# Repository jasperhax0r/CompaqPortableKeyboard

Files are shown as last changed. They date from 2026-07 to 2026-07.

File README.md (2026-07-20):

# Compaq Portable Keyboard — Replacement PCB, Firmware & Protocol

A drop-in replacement keyboard controller for the **Compaq Portable** (1983),
built around a Raspberry Pi Pico. It reads an 83-key diode matrix and speaks the
machine's native **IBM XT (scancode set 1)** protocol over the original 2×3
keyboard connector.

The repo also contains a **USB-serial / PS-2 test rig** used during bring-up, and
— probably the most useful part for other people — a **scope-verified writeup of
the Compaq Portable keyboard protocol**, which as far as I can tell isn't
documented anywhere else public.

Everything here is hand-solderable through-hole where possible, on purpose. The
only surface-mount parts are the two level-shifter buffers, and even those have a
through-hole alternative described in the build notes.

---

## Why this exists

The original keyboard PCBs are getting old, and the matrix routing on the
factory board is... a journey. This recreates the keyboard's electrical behavior
faithfully enough that the machine POSTs and types exactly as it did in 1983,
while letting you rebuild the board with a $15 iron and a solder sucker.

The first PCB revision is a **faithful recreation** of the original layout, on
purpose — it's a known-good reference. A rev2 with layout improvements is planned
(see `docs/rev2-notes.md`).

---

## Repository layout

```
/firmware        Pico firmware (CircuitPython)
  code.py          matrix-scan keyboard firmware (the real thing)
  test-rig/        USB-serial + PS-2 bring-up firmware
/hardware        KiCad project, schematic, PCB, Gerbers
/models          3D-printable STLs (connector keyway + fitment shims)
/tools           protocol decoder + KLE matrix-annotation scripts
  xtframe.py       decode a logic-analyzer CSV into XT scancodes
  kle_annotate.py  annotate a raw KLE layout with matrix coordinates
/docs            protocol writeup, build notes, rev2 log
```

---

## How it works

The Pico scans a **10×10 diode matrix** (83 keys, one diode per key, so full
NKRO) and emits XT scancodes on the keyboard connector.

**Power:** the Compaq feeds ~12 V down the cable. An onboard 7805 drops that to
5 V for the buffers, and the Pico runs from that 5 V into VSYS through a Schottky.
The board reproduces the original's protection: reverse-polarity Schottky, a
polyfuse, TVS clamps at the connector, and a 5.6 V crowbar across the 5 V rail.

**Level shifting:** the Pico is 3.3 V and **not** 5 V tolerant. Outbound
clock/data go through an **SN74LVC07A** (open-drain, pulled to 5 V). Inbound
reset and clock-sense come back through an **SN74LVC14A** Schmitt-trigger
cascade — the hysteresis matters, see the protocol notes on line ringing.

**Protocol:** XT scancode set 1. The keyboard generates the clock; each frame is
one start bit plus 8 data bits, LSB first, with data valid on the falling clock
edge, at roughly 24 kHz. On reset release the keyboard waits ~170 ms then sends
`0xAA` (self-test passed). Full details and scope captures in
[`docs/protocol.md`](docs/protocol.md).

---

## Building the firmware

The firmware is **CircuitPython** — no toolchain, no compile step.

1. Flash CircuitPython to the Pico.
2. Copy `firmware/code.py` to the `CIRCUITPY` drive as `code.py`.
3. That's it — it runs on boot.

### Bring-up before you install it

`code.py` has debug switches at the top:

- `DEBUG = True` prints every key make/break to the USB serial console.
- `RAW_SCAN = True` prints the raw `(row, col)` of every press, ignoring the
  keymap — use this to verify your matrix wiring against the board.
- `XT_CONNECTED = False` scans and prints but does **not** drive the XT lines,
  so you can validate the whole matrix over USB with nothing connected to the
  Compaq.

Walk every key with `RAW_SCAN = True` and confirm it matches the board before
trusting the scancode map. When it checks out, set all three back to
`DEBUG = False`, `RAW_SCAN = False`, `XT_CONNECTED = True`.

> **Note on the matrix map:** this board is wired to the *original Compaq's*
> matrix order (a straight sequential fill), **not** the interleaved mapping a
> tool like `kbplacer` produces from the KLE. If you regenerate the keymap from
> the layout file you'll get the wrong table. The map in `code.py` is the
> authoritative one — it was verified key-by-key against the physical board.

---

## Building the board

See [`docs/build.md`](docs/build.md) for the full walkthrough. The short version:

1. **Populate and verify the regulator section first.** Confirm 5.0 V at the rail
   *and* at the buffer VCC pins before any logic sees power.
2. **Power up on a current-limited bench supply** (~150 mA limit) for the first
   power-on. A wiring fault then shows as the supply hitting its limit at ~0 V,
   instead of as a hot regulator and a burn. (Ask me how I know.)
3. Then the Pico, then the level shifters, then the matrix.

The two `SN74LVC0x` buffers are TSSOP — the only fine-pitch parts. Drag-solder
with plenty of flux and wick any bridges. If you'd rather stay all-through-hole,
`docs/build.md` covers a `7407` + `CD4050B` DIP alternative (you lose the Schmitt
hysteresis on the input side, fine for a short cable).

---

## The 3D-printed parts

`/models` has the connector **keyway** (the original connector is mechanically
keyed; the print replicates that so the plug can't seat rotated — important,
since a rotated plug puts 12 V onto a signal line) and **fitment shims**.

Print in any rigid filament. PETG or ABS if it'll sit near the warm regulator;
PLA is fine otherwise.

---

## Tools

`tools/xtframe.py` decodes a logic-analyzer CSV (start bit + 8 data LSB-first,
falling-edge sampled) into XT scancodes, with a `--deglitch-us` option to reject
sub-threshold ringing on a passive tap. It was used to reverse-engineer the
protocol; it's handy for anyone probing an XT-family keyboard.

`tools/kle_annotate.py` annotates a raw [keyboard-layout-editor](https://www.keyboard-layout-editor.com)
JSON with matrix coordinates.

---

## Status

Working. The board POSTs and types on a real Compaq Portable. Known rev1
warts and the planned rev2 fixes are logged in [`docs/rev2-notes.md`](docs/rev2-notes.md)
(regulator thermal pad, hand-solder footprints, silkscreen polarity markers,
axial diode on the 5 V rail, and more).

---

## Licenses

This project is open-source hardware. Different parts carry different licenses,
because software, hardware, and documentation are legally distinct:

| Part | License |
|---|---|
| Firmware & tools (`/firmware`, `/tools`) | **MIT** |
| Hardware & 3D models (`/hardware`, `/models`) | **CERN-OHL-S v2** |
| Documentation (`/docs`, this README) | **CC-BY-4.0** |

- The **firmware** is MIT — use it however you like.
- The **board and STL designs** are CERN-OHL-S (strongly reciprocal): if you
  make and distribute modified hardware, keep the design files open under the
  same terms.
- The **documentation and protocol writeup** are CC-BY-4.0 — reproduce and build
  on them, with attribution.

Full texts are in `/LICENSES`. See CERN-OHL-S §3 for the source-availability
requirement when distributing hardware based on this design.

---

## Acknowledgements

Original Compaq Portable schematic reference: Howard W. Sams & Co.
Computerfacts, 1987 (used for cross-referencing switch designations during
reverse engineering).

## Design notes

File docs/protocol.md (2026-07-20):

# Compaq Portable Keyboard Protocol

A scope-verified description of the keyboard protocol used by the **Compaq
Portable** (1983). Everything here was measured on a working original keyboard
with a logic analyzer, not taken from a datasheet — where a number is quoted, it
came off the wire.

The short version: it's **IBM XT (scancode set 1)**, clocked by the keyboard,
with one detail that trips people up (see [Reset](#reset-active-low-host-driven)).

---

## Connector

The keyboard attaches with a **2×3 connector** (AMP), of which **5 of 6
positions are populated**. It is **mechanically keyed** — the housing physically
prevents the plug from seating rotated. This matters: the +12 V and signal pins
are adjacent, so a rotated plug would put 12 V onto a logic line.

| Pin | Function |
|-----|---|
| 1 | CLOCK |
| 2 | DATA |
| 3 | RESET |
| 4 | *(unpopulated)* |
| 5 | +12 V |
| 6 | GND |

> Pin numbering follows the board footprint. The clock/data assignment
> (pin 1 = clock, pin 2 = data) was **confirmed on the scope** — it is the
> reverse of what you might guess from the schematic, so verify before trusting
> a pinout diagram.

The unpopulated position (pin 4) has no conductor; the single ground is on pin 6.
Because the connector is keyed, there is no polarity protection from the pinout
itself — the board provides reverse-polarity protection instead.

---

## Electrical

- **12 V** supply down the cable. Everything on the keyboard PCB runs on 5 V
  behind a 78M05 regulator; the logic is 5 V.
- CLOCK and DATA are **open-collector, idle high**, with pull-ups on the
  keyboard board (~3.3 kΩ) and Schmitt-trigger receivers (74LS132 on the
  original). The Schmitt hysteresis is not decorative — see
  [Signal integrity](#signal-integrity).
- The keyboard's controller is an **8048-family** microcontroller
  (mask part `22-908-03A`) on a 4.6 MHz crystal — the same family as the
  IBM XT keyboard. The `RESET`, `PSEN`, and `ALE` pin labels on the schematic
  match an 8048 exactly (Compaq renamed ALE to "KBALE").

---

## Frame format

The **keyboard generates the clock.** Each byte is sent as:

```
        start   d0   d1   d2   d3   d4   d5   d6   d7
DATA  ──┐ 1  ┌──┐    ┌────┐ ...                      idle high
        └────┘  └────┘    └──
CLOCK ─┐  ┌─┐  ┌─┐  ┌─┐  ┌─┐  ...   ┌─────────────── idle high
       └──┘ └──┘ └──┘ └──┘ └──┘     ┘
         ^    ^    ^    ^
       data sampled on each FALLING edge
```

- **1 start bit** (value `1`), then **8 data bits, LSB first**.
- **Data is valid on the falling edge of CLOCK** — the host samples there.
- Idle state is CLOCK high, DATA high.

Measured bit period during a real transmission: **~41 µs (≈24.3 kHz)**. The host
is edge-driven, not timed, so exact frequency is not critical — but reproduce
the frame *shape* and edge relationship.

### Scancodes

Standard **XT scancode set 1**. A key press sends its **make code**; a key
release sends the **break code**, which is `make | 0x80` (bit 7 set).

Example, verified on the wire (key `A`):

```
make  0x1E
break 0x9E     (0x1E | 0x80)
```

The full make-code table for this keyboard is in the firmware
(`firmware/code.py`, the `KEYMAP` dict). Note that the *matrix position* → key
mapping is specific to this board's wiring; the *scancodes* are stock XT set 1.

---

## Reset (active-low, host-driven)

This is the detail that isn't obvious and will cost you an afternoon if you get
it wrong.

**RESET is active low and driven by the host**, not by the keyboard. The host
holds the line **low** during power-up and **releases it high** when it is ready
for the keyboard. On the original board this same node also carries the
keyboard's own power-on reset RC (≈33 kΩ / 39 µF), so it serves double duty.

For an emulator you do not have an 8048 reset pin to hold — you only need to
**read** this line and react to the low→high transition.

| Line state | Meaning |
|---|---|
| LOW  | host asserting reset — do not transmit |
| HIGH | normal operation |

---

## Power-on handshake (BAT)

Captured cold-boot sequence, keyboard attached, from power-on:

1. Host holds **RESET low** from power-on.
2. The keyboard's 8048 boots and emits a brief burst of clock/data garbage
   **while reset is still low** (the host isn't listening yet — ignore it).
3. Host **releases RESET high**.
4. The keyboard waits **~172 ms**, then clocks out **`0xAA`** (BAT — basic
   assurance test passed): start bit + `0xAA` LSB-first, falling-edge data,
   at 24.3 kHz.
5. The host accepts it and POST continues.

The ~172 ms delay is real and matters — some XT-family BIOSes miss the BAT byte
if it arrives too soon after reset release. Reproduce the delay.

```
reset released:  t = 2.5198 s
BAT frame (0xAA): t = 2.6916 s
delay:           172 ms
```

Raw capture: [`captures/keyboardboot.csv`](captures/keyboardboot.csv).

---

## Host inhibit

XT clock is bidirectional in the sense that the **host can pull CLOCK low to
inhibit** the keyboard (tell it to hold transmission). The 8048 reads the clock
line back on its `T1` test input to see this. An emulator should likewise sense
the clock line and buffer keystrokes while the host is holding it low, sending
them once the line is released.

---

## Signal integrity

During reverse engineering, some captured frames showed **extra clock edges** —
10 or 11 edges where a clean frame has 9 — decoding to garbage. These were not
keyboard faults. The keyboard's clock line **rings**, and a logic analyzer
sampling against a single threshold catches the sub-threshold crossings that the
original's **74LS132 Schmitt-trigger receivers reject**.

Two lessons:

1. When decoding captures from a passive tap, deglitch the clock edges (reject
   any falling edge closer than ~20 µs to the previous one — a real bit is
   ~41 µs). `tools/xtframe.py --deglitch-us 20` does this.
2. **Any receiver for this signal needs Schmitt hysteresis.** The replacement
   board uses an SN74LVC14A on the clock-sense and reset inputs for exactly this
   reason. A plain buffer would pass the ringing straight through.

This also explains the original's design: the series diodes and the 33 pF cap on
the reset line, and the 3.3 kΩ pull-ups, are all there to damp a two-foot coiled
cable running next to a CRT. Keep that philosophy — slow, weak, and damped is
what makes this link reliable. Don't speed up the edges.

---

## Decoding your own captures

`tools/xtframe.py` takes a logic-analyzer CSV with columns
`Time[s], CLOCK, DATA, RESET` and prints decoded scancodes:

```
python3 xtframe.py capture.csv --deglitch-us 20
```

It reports reset edges, clusters frames on inter-frame gaps, samples DATA on each
CLOCK falling edge, checks the start bit, and decodes LSB-first to a byte. A
frame with more than 9 edges or non-uniform bit periods is a glitch artifact, not
a scancode.

---

## Summary table

| Property | Value |
|---|---|
| Encoding | XT scancode set 1 |
| Clock source | keyboard |
| Bit order | LSB first |
| Frame | 1 start bit + 8 data bits |
| Data valid | falling edge of CLOCK |
| Bit rate | ~24.3 kHz (~41 µs/bit) |
| Idle | CLOCK high, DATA high |
| Break code | make \| 0x80 |
| Reset | active low, host-driven |
| Power-on | ~172 ms after reset release, send 0xAA |
| Host inhibit | host pulls CLOCK low; keyboard senses and buffers |

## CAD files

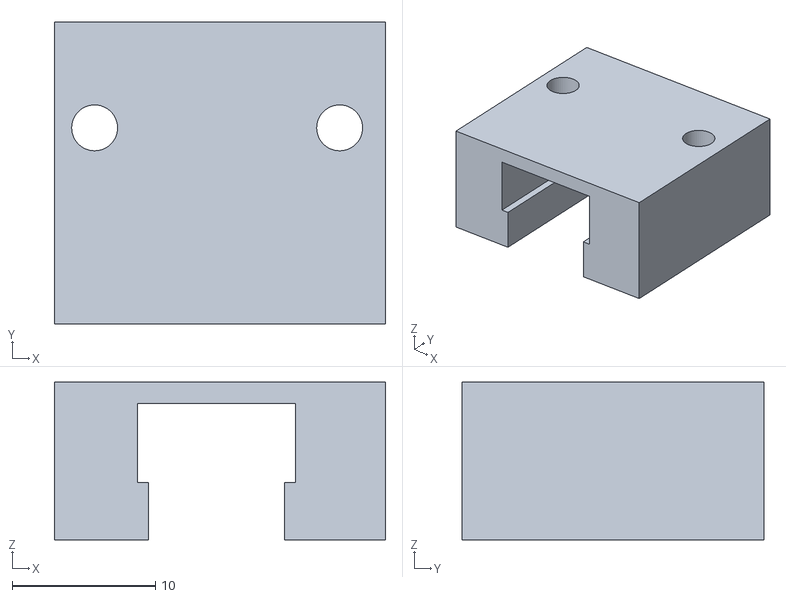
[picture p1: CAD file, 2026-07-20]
models/Port.stl
23.1 x 21.1 x 11.0

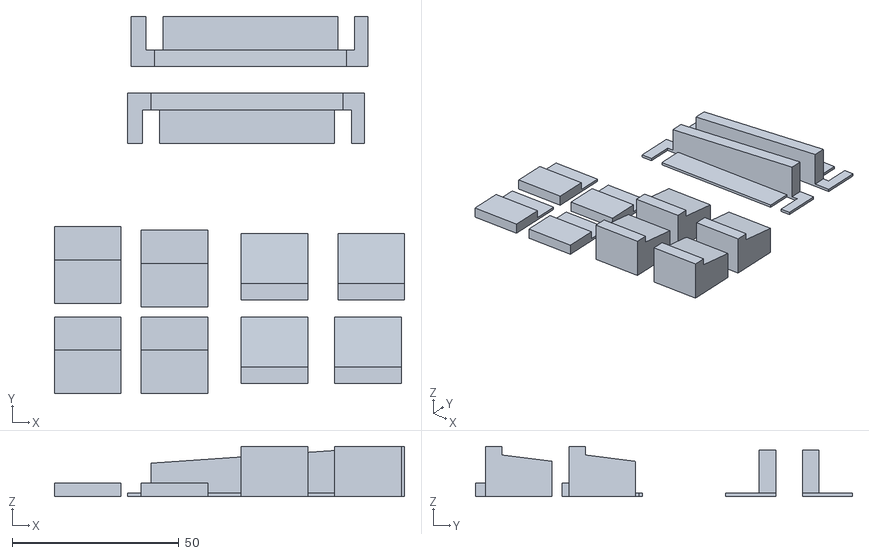
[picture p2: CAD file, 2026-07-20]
models/Shims.stl
105.0 x 113.0 x 15.0

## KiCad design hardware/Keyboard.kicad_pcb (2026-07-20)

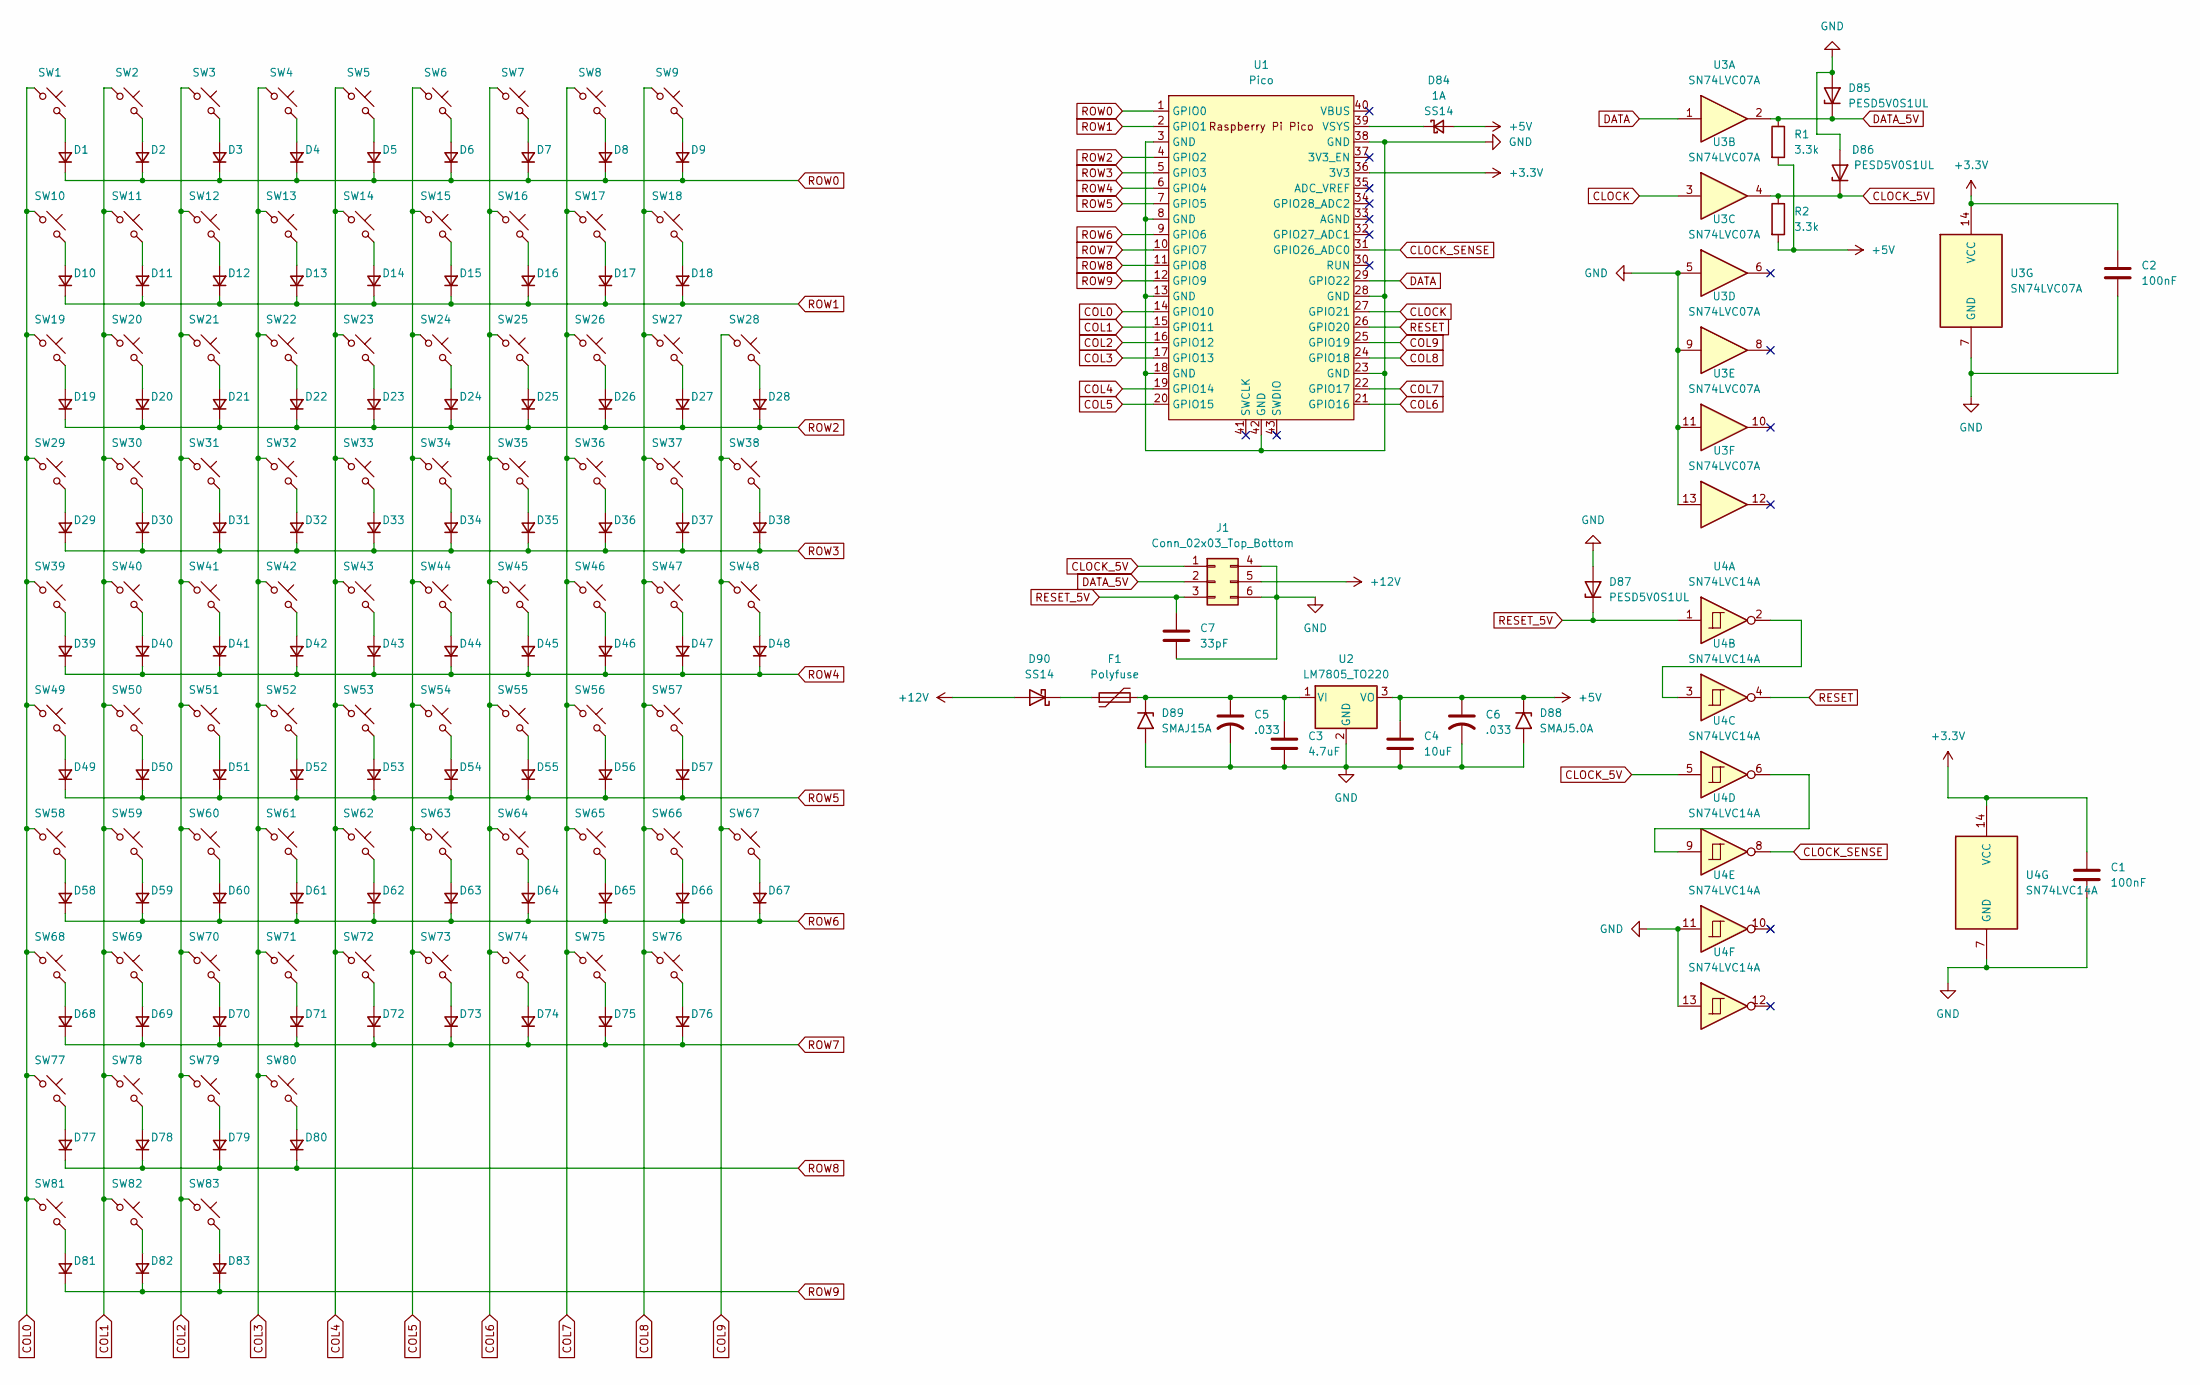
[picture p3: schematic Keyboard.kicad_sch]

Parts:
C1, C2: 100nF; C_Disc_D5.0mm_W2.5mm_P5.00mm
C3: 4.7uF; C_Disc_D5.0mm_W2.5mm_P5.00mm
C4: 10uF; C_Disc_D5.0mm_W2.5mm_P5.00mm
C5, C6: .033; C_Disc_D5.0mm_W2.5mm_P5.00mm
C7: 33pF; C_Disc_D5.0mm_W2.5mm_P5.00mm
D1, D2, D3, D4, D5, D6, D7, D8, D9, D10, D11, D12, D13, D14, D15, D16, D17, D18, D19, D20, D21, D22, D23, D24, D25, D26, D27, D28, D29, D30, D31, D32, D33, D34, D35, D36, D37, D38, D39, D40, D41, D42, D43, D44, D45, D46, D47, D48, D49, D50, D51, D52, D53, D54, D55, D56, D57, D58, D59, D60, D61, D62, D63, D64, D65, D66, D67, D68, D69, D70, D71, D72, D73, D74, D75, D76, D77, D78, D79, D80, D81, D82, D83: D; D_SOD-123F
D84: 1A; D_5KPW_P12.70mm_Horizontal
D85, D86, D87: PESD5V0S1UL; D_SOD-882
D88: SMAJ5.0A; D_SMA
D89: SMAJ15A; D_SMA
D90: SS14; D_SMA
F1: Polyfuse; C_Disc_D5.0mm_W2.5mm_P5.00mm
J1: Conn_02x03_Top_Bottom; PinHeader_2x03_P2.54mm_Horizontal
R1, R2: 3.3k; R_Axial_DIN0207_L6.3mm_D2.5mm_P7.62mm_Horizontal
SW1, SW2, SW3, SW4, SW5, SW6, SW7, SW8, SW9, SW10, SW11, SW12, SW13, SW14, SW15, SW16, SW17, SW18, SW19, SW20, SW21, SW22, SW23, SW24, SW25, SW26, SW27, SW28, SW29, SW30, SW31, SW32, SW33, SW34, SW35, SW36, SW37, SW38, SW39, SW40, SW41, SW42, SW43, SW44, SW45, SW46, SW47, SW48, SW49, SW50, SW51, SW52, SW53, SW54, SW55, SW56, SW57, SW58, SW59, SW60, SW61, SW62, SW63, SW64, SW65, SW66, SW67, SW68, SW69, SW70, SW71, SW72, SW73, SW74, SW75, SW76, SW77, SW78, SW79, SW81, SW82, SW83: SW_Push; SW_Cherry_MX_1.00u_PCB
SW80: SW_Push; SW_Cherry_MX_6.25u_PCB
U1: Pico; RPi_Pico_SMD_TH
U2: LM7805_TO220; TO-220-3_Vertical
U3: SN74LVC07A; TSSOP-14_4.4x5mm_P0.65mm
U4: SN74LVC14A; TSSOP-14_4.4x5mm_P0.65mm

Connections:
+3.3V: C1.1, C2.1, U1.36 (3V3), U3.14 (VCC), U4.14 (VCC)
+5V: C4.1, C6.1, D84.2 (A), D88.1 (A1), R1.2, R2.2, U2.3 (VO)
+12V: D90.2 (A), J1.5
CLOCK: U1.27 (GPIO21), U3.3
CLOCK_5V: D86.1 (K), J1.1, R2.1, U3.4, U4.5
CLOCK_SENSE: U1.31 (GPIO26_ADC0), U4.8
COL0: SW1.1, SW10.1, SW19.1, SW29.1, SW39.1, SW49.1, SW58.1, SW68.1, SW77.1, SW81.1, U1.14 (GPIO10)
COL1: SW2.1, SW11.1, SW20.1, SW30.1, SW40.1, SW50.1, SW59.1, SW69.1, SW78.1, SW82.1, U1.15 (GPIO11)
COL2: SW3.1, SW12.1, SW21.1, SW31.1, SW41.1, SW51.1, SW60.1, SW70.1, SW79.1, SW83.1, U1.16 (GPIO12)
COL3: SW4.1, SW13.1, SW22.1, SW32.1, SW42.1, SW52.1, SW61.1, SW71.1, SW80.1, U1.17 (GPIO13)
COL4: SW5.1, SW14.1, SW23.1, SW33.1, SW43.1, SW53.1, SW62.1, SW72.1, U1.19 (GPIO14)
COL5: SW6.1, SW15.1, SW24.1, SW34.1, SW44.1, SW54.1, SW63.1, SW73.1, U1.20 (GPIO15)
COL6: SW7.1, SW16.1, SW25.1, SW35.1, SW45.1, SW55.1, SW64.1, SW74.1, U1.21 (GPIO16)
COL7: SW8.1, SW17.1, SW26.1, SW36.1, SW46.1, SW56.1, SW65.1, SW75.1, U1.22 (GPIO17)
COL8: SW9.1, SW18.1, SW27.1, SW37.1, SW47.1, SW57.1, SW66.1, SW76.1, U1.24 (GPIO18)
COL9: SW28.1, SW38.1, SW48.1, SW67.1, U1.25 (GPIO19)
DATA: U1.29 (GPIO22), U3.1
DATA_5V: D85.1 (K), J1.2, R1.1, U3.2
GND: C1.2, C2.2, C3.2, C4.2, C5.2, C6.2, C7.2, D85.2 (A), D86.2 (A), D87.2 (A), D88.2 (A2), D89.2 (A2), J1.4, J1.6, U1.3 (GND), U1.8 (GND), U1.13 (GND), U1.18 (GND), U1.23 (GND), U1.28 (GND), U1.38 (GND), U1.42 (GND), U2.2 (GND), U3.5, U3.7 (GND), U3.9, U3.11, U3.13, U4.7 (GND), U4.11, U4.13
unnamed: D1.2 (A), SW1.2
unnamed: D2.2 (A), SW2.2
unnamed: D3.2 (A), SW3.2
unnamed: D4.2 (A), SW4.2
unnamed: D5.2 (A), SW5.2
unnamed: D6.2 (A), SW6.2
unnamed: D7.2 (A), SW7.2
unnamed: D8.2 (A), SW8.2
unnamed: D9.2 (A), SW9.2
unnamed: D10.2 (A), SW10.2
unnamed: D11.2 (A), SW11.2
unnamed: D12.2 (A), SW12.2
unnamed: D13.2 (A), SW13.2
unnamed: D14.2 (A), SW14.2
unnamed: D15.2 (A), SW15.2
unnamed: D16.2 (A), SW16.2
unnamed: D17.2 (A), SW17.2
unnamed: D18.2 (A), SW18.2
unnamed: D19.2 (A), SW19.2
unnamed: D20.2 (A), SW20.2
unnamed: D21.2 (A), SW21.2
unnamed: D22.2 (A), SW22.2
unnamed: D23.2 (A), SW23.2
unnamed: D24.2 (A), SW24.2
unnamed: D25.2 (A), SW25.2
unnamed: D26.2 (A), SW26.2
unnamed: D27.2 (A), SW27.2
unnamed: D28.2 (A), SW28.2
unnamed: D29.2 (A), SW29.2
unnamed: D30.2 (A), SW30.2
unnamed: D31.2 (A), SW31.2
unnamed: D32.2 (A), SW32.2
unnamed: D33.2 (A), SW33.2
unnamed: D34.2 (A), SW34.2
unnamed: D35.2 (A), SW35.2
unnamed: D36.2 (A), SW36.2
unnamed: D37.2 (A), SW37.2
unnamed: D38.2 (A), SW38.2
unnamed: D39.2 (A), SW39.2
unnamed: D40.2 (A), SW40.2
unnamed: D41.2 (A), SW41.2
unnamed: D42.2 (A), SW42.2
unnamed: D43.2 (A), SW43.2
unnamed: D44.2 (A), SW44.2
unnamed: D45.2 (A), SW45.2
unnamed: D46.2 (A), SW46.2
unnamed: D47.2 (A), SW47.2
unnamed: D48.2 (A), SW48.2
unnamed: D49.2 (A), SW49.2
unnamed: D50.2 (A), SW50.2
unnamed: D51.2 (A), SW51.2
unnamed: D52.2 (A), SW52.2
unnamed: D53.2 (A), SW53.2
unnamed: D54.2 (A), SW54.2
unnamed: D55.2 (A), SW55.2
unnamed: D56.2 (A), SW56.2
unnamed: D57.2 (A), SW57.2
unnamed: D58.2 (A), SW58.2
unnamed: D59.2 (A), SW59.2
unnamed: D60.2 (A), SW60.2
unnamed: D61.2 (A), SW61.2
unnamed: D62.2 (A), SW62.2
unnamed: D63.2 (A), SW63.2
unnamed: D64.2 (A), SW64.2
unnamed: D65.2 (A), SW65.2
unnamed: D66.2 (A), SW66.2
unnamed: D67.2 (A), SW67.2
unnamed: D68.2 (A), SW68.2
unnamed: D69.2 (A), SW69.2
unnamed: D70.2 (A), SW70.2
unnamed: D71.2 (A), SW71.2
unnamed: D72.2 (A), SW72.2
unnamed: D73.2 (A), SW73.2
unnamed: D74.2 (A), SW74.2
unnamed: D75.2 (A), SW75.2
unnamed: D76.2 (A), SW76.2
unnamed: D77.2 (A), SW77.2
unnamed: D78.2 (A), SW78.2
unnamed: D79.2 (A), SW79.2
unnamed: D80.2 (A), SW80.2
unnamed: D81.2 (A), SW81.2
unnamed: D82.2 (A), SW82.2
unnamed: D83.2 (A), SW83.2
unnamed: D84.1 (K), U1.39 (VSYS)
unnamed: C3.1, C5.1, D89.1 (A1), F1.2, U2.1 (VI)
unnamed: D90.1 (K), F1.1
unnamed: U4.2, U4.3
unnamed: U4.6, U4.9
RESET: U1.26 (GPIO20), U4.4
RESET_5V: C7.1, D87.1 (K), J1.3, U4.1
ROW0: D1.1 (K), D2.1 (K), D3.1 (K), D4.1 (K), D5.1 (K), D6.1 (K), D7.1 (K), D8.1 (K), D9.1 (K), U1.1 (GPIO0)
ROW1: D10.1 (K), D11.1 (K), D12.1 (K), D13.1 (K), D14.1 (K), D15.1 (K), D16.1 (K), D17.1 (K), D18.1 (K), U1.2 (GPIO1)
ROW2: D19.1 (K), D20.1 (K), D21.1 (K), D22.1 (K), D23.1 (K), D24.1 (K), D25.1 (K), D26.1 (K), D27.1 (K), D28.1 (K), U1.4 (GPIO2)
ROW3: D29.1 (K), D30.1 (K), D31.1 (K), D32.1 (K), D33.1 (K), D34.1 (K), D35.1 (K), D36.1 (K), D37.1 (K), D38.1 (K), U1.5 (GPIO3)
ROW4: D39.1 (K), D40.1 (K), D41.1 (K), D42.1 (K), D43.1 (K), D44.1 (K), D45.1 (K), D46.1 (K), D47.1 (K), D48.1 (K), U1.6 (GPIO4)
ROW5: D49.1 (K), D50.1 (K), D51.1 (K), D52.1 (K), D53.1 (K), D54.1 (K), D55.1 (K), D56.1 (K), D57.1 (K), U1.7 (GPIO5)
ROW6: D58.1 (K), D59.1 (K), D60.1 (K), D61.1 (K), D62.1 (K), D63.1 (K), D64.1 (K), D65.1 (K), D66.1 (K), D67.1 (K), U1.9 (GPIO6)
ROW7: D68.1 (K), D69.1 (K), D70.1 (K), D71.1 (K), D72.1 (K), D73.1 (K), D74.1 (K), D75.1 (K), D76.1 (K), U1.10 (GPIO7)
ROW8: D77.1 (K), D78.1 (K), D79.1 (K), D80.1 (K), U1.11 (GPIO8)
ROW9: D81.1 (K), D82.1 (K), D83.1 (K), U1.12 (GPIO9)

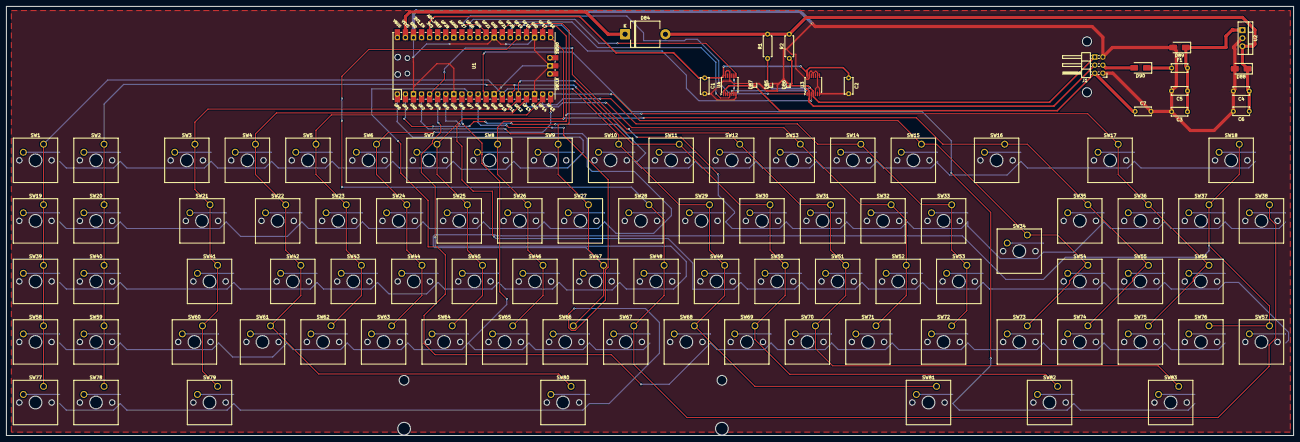
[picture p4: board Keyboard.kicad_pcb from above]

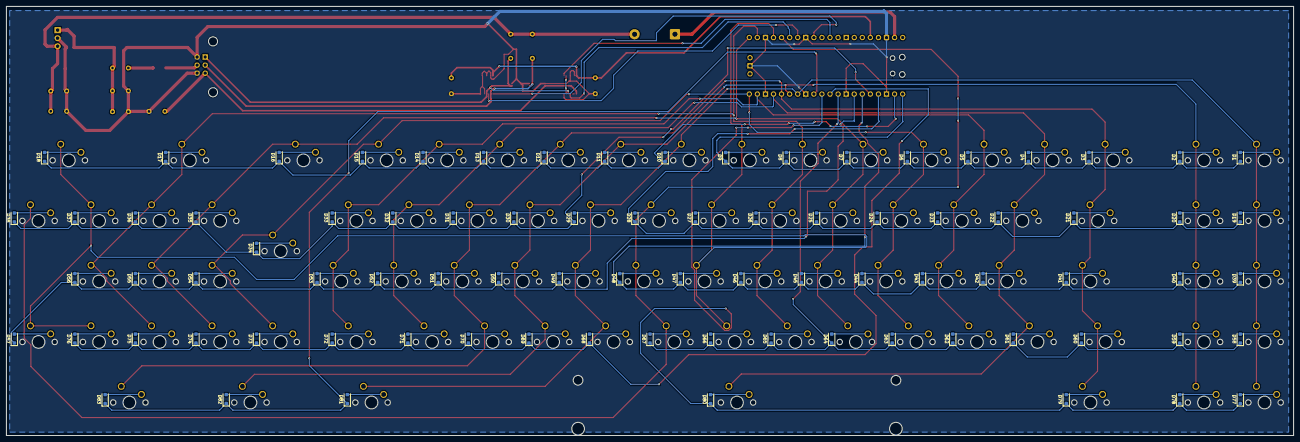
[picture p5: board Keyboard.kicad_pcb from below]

Board: 2 copper layers, 405.0 x 135.0 mm, 188 parts (83 on the bottom side), 119 nets.

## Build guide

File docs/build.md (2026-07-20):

# Build Guide

Assembly and bring-up for the Compaq Portable replacement keyboard PCB. The
board is designed to be hand-solderable; the only fine-pitch parts are the two
level-shifter buffers, and there's a through-hole alternative for those below.

Read the [safety note](#a-word-on-first-power-up) before you apply power the
first time — it's the difference between finding a fault on a meter and finding
it with your fingertip.

\---

## Tools \& consumables

* Soldering iron with a **chisel/C tip** (not a fine conical — you'll fight the
ground planes), \~370 °C / 700 °F for the plane-connected pins
* Solder, **flux** (liquid or gel — essential for the TSSOP buffers), solder wick
* Solder sucker for through-hole rework
* Multimeter with continuity/diode mode
* **A current-limited bench supply** for first power-up (strongly recommended —
see below)
* Kapton tape (holds the fine-pitch chips while you tack them)

\---

## Bill of materials notes

Most of the board is through-hole on purpose. Key parts:

* **Regulator:** 7805 (TO-220). At the board's \~60 mA load it dissipates well
under half a watt and needs no heatsink. (A TO-220 was chosen for parts
availability; rev2 moves to a copper-pour thermal pad — see `rev2-notes.md`.)
* **Level shifters:** `SN74LVC07A` (open-drain, outbound clock/data) and
`SN74LVC14A` (Schmitt, inbound reset/clock-sense). TSSOP-14.
* **Rail protection:** reverse-polarity Schottky (SS14), polyfuse, TVS clamps at
the connector, and a 5 V crowbar (SMAJ5.0A) across the rail.
* **Matrix:** 83 switches, one diode each (1N4148-class), COL2ROW with cathodes
on the rows.
* **MCU:** Raspberry Pi Pico, on headers so it can be programmed before install.

### All-through-hole option

If you want to avoid SMD entirely, the two LVC buffers can be replaced with DIP
parts:

* `SN74LVC07A` → **7407** (hex open-collector buffer, DIP-14)
* `SN74LVC14A` → **CD4050B** (hex buffer, DIP-16; its inputs tolerate 5 V when
run at 3.3 V, so it level-shifts inbound cleanly)

You lose the Schmitt hysteresis on the input side. On a short bench cable that's
fine; on the full coiled cable the hysteresis helps reject ringing (see
`protocol.md`), so socket them and keep the option open.

\---

## Soldering the fine-pitch buffers

The two `SN74LVC0x` are the only hard parts. Technique:

1. **Flux the pads heavily**, then tack one corner pin to hold the chip square.
Kapton tape across the body helps hold it while you tack.
2. Tack the diagonal corner. Now it's located; both hands are free.
3. **Drag-solder** each row, or deliberately blob all pins and **wick the excess
off** — the flux pulls solder to the pins and releases the bridge to the wick.
Either works; the blob-and-wick is very forgiving.
4. Inspect under magnification and buzz **every adjacent pin pair** for bridges,
and each pin to its destination for opens — *before* powering anything.

The ground planes suck heat. Use a big tip, run hot, and touch briefly — a quick
hot touch dumps less total heat into the board than a cool tip lingering.

\---

## Assembly order

Populate in this order so each stage sits on a verified foundation:

### 1\. Regulator section first

Populate the 7805, its input/output caps, and the rail protection. **Do not
populate anything else yet.**

Apply 12 V and confirm:

* **5.0 V at the rail**, and
* **5.0 V at the buffer VCC pins** (where the LVC chips will sit).

If the rail is wrong, you find out with nothing downstream to damage.

> \*\*Watch diode orientation on the 5 V rail.\*\* A reversed rail diode is a dead
> short across the regulator. The etched cathode marks on small SMD diodes are
> genuinely hard to read (dark on black); verify orientation with the meter's
> diode mode, not just by eye. (Rev2 uses an axial diode with a visible band
> here for exactly this reason.)

### 2\. Pico

Seat the Pico (on headers). Confirm 3.3 V on its 3V3 pin and that the 5 V→VSYS
Schottky is feeding it.

### 3\. Level shifters

Populate the LVC buffers (or DIP alternatives). Re-verify VCC and grounds.

### 4\. Matrix

Switches and diodes. All the same orientation — COL2ROW, diode cathodes toward
the rows.

\---

## A word on first power-up

**Use a current-limited bench supply set to \~150 mA for the first power-on of
each stage.** A wiring fault then shows up as the supply pegging to its current
limit at near-zero volts — instantly, silently, with no heat. Without a limit,
the same fault dumps its power into the regulator as heat; a shorted 7805 gets
hot enough to burn you before you've found the problem.

If you only have a fixed 12 V supply, at least watch the current draw: 12 V in
pulling 400 mA at idle means something is wrong — kill it and investigate before
touching the board.

\---

## Firmware bring-up

The firmware is CircuitPython — flash CircuitPython, then copy `firmware/code.py`
to the `CIRCUITPY` drive.

`code.py` has three switches at the top for bring-up:

```python
DEBUG        = True    # print key make/break to USB serial
RAW\_SCAN     = True    # print raw (row,col) of every press, ignore keymap
XT\_CONNECTED = False   # scan/print only; do NOT drive the XT lines
```

### Step 1 — verify the matrix over USB (nothing connected to the Compaq)

Set `RAW\_SCAN = True`, `XT\_CONNECTED = False`. Open the serial console and press
**every key**, in physical order. Each press prints `row N col M`. Confirm the
map matches your board — this catches a swapped row/column or a solder-bridged
diode while it's trivial to fix, with zero risk to anything.

If **every** key reads pressed (or none do), the scan polarity is inverted — flip
the drive/sense sense noted in `scan\_and\_emit()`.

### Step 2 — connect and go live

When the matrix checks out, set:

```python
DEBUG        = False
RAW\_SCAN     = False
XT\_CONNECTED = True
```

Plug into the Compaq. It should POST off the BAT handshake and type. For one
final confidence pass you can leave `DEBUG = True` with `XT\_CONNECTED = True` —
you'll see makes/breaks *and* the machine will type — then set `DEBUG = False`
for the quiet production build (the prints cost scan time).

\---

## Troubleshooting

**Keys scan correctly (RAW\_SCAN looks right) but the Compaq gets garbage, and
the same key gives *different* random results each time.**
The XT output isn't being driven to a solid high — the clock/data pins must be
**push-pull** (they drive the LVC07A's CMOS input; there's no pull-up on that
net). If you ported config from the BSS138 test rig, it was set to open-drain
there — change it. Confirm with a scope on the Pico's clock pin: you want a clean
0↔3.3 V square wave, not a ragged/floating high.

**Nothing registers; serial shows `queue full, dropping`.**
`xt\_ready()` is returning false, so nothing transmits and the send queue backs
up. Check that **RESET (input) reads high** with the machine running, and that
**CLOCK\_SENSE idles high**. A stuck-low reset or clock-sense blocks all sends.

**Keys lag / need to be held.**
Debounce too aggressive for your switches, or the scan interval is stretched.
Lower `DEBOUNCE\_SCANS` (try 1) and reduce the per-row settle. If it still drags
under fast typing, the XT transmit time between scans is the cost — scan more
often than you send.

**Machine throws a keyboard POST error (e.g. 301).**
The BAT handshake isn't landing. Confirm the \~172 ms delay after reset release
before `0xAA` (some BIOSes miss it if it's too early), and that reset polarity is
read correctly (active low).

**Occasional wrong/garbled keys under a marginal cable.**
Ringing on the clock line. Make sure the input path uses the Schmitt buffer
(`SN74LVC14A`), keep the connector-side TVS/cap, and don't speed up the edges.
See the signal-integrity section of `protocol.md`.

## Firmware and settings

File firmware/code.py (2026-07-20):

# code.py  --  Compaq Portable keyboard firmware (FINAL BOARD)
#
# CircuitPython on the onboard Raspberry Pi Pico. Scans the 10x10 diode
# matrix and emits IBM XT (Set 1) scancodes on the keyboard connector.
# Full NKRO (every key has its own diode). No PS/2, no translation --
# this reads physical keys and speaks XT directly.
#
# --- pin map (from the board schematic) ---
# Rows  ROW0..9  = GP0..GP9      (driven low one at a time)
# Cols  COL0..9  = GP10..GP19    (inputs, pull-up; pressed reads LOW)
# XT    CLOCK        = GP21  open-drain out
#       DATA         = GP22  open-drain out
#       RESET        = GP20  input  (host drives; active LOW)
#       CLOCK_SENSE  = GP26  input  (reads XT clock; host inhibit = low)
# LED   onboard      = board.LED   (stands in for a Caps Lock lamp)
#
# Matrix is COL2ROW (diode cathodes on the rows): drive a row LOW, the
# pressed key pulls its column LOW through the forward diode. If EVERY key
# reads pressed or none do, the drive/sense polarity is inverted -- flip
# ROW_ACTIVE / the pressed test below.

import board
import digitalio
import supervisor
import sys
import time

# ----------------------------------------------------------------- timing
HALF_US = 20            # XT half clock period (~24 kHz nominal)
SETUP_US = 5            # XT data setup before falling edge
BAT_DELAY_MS = 170      # keyboard's wait after reset release, then 0xAA
DEBOUNCE_SCANS = 2      # scans a change must persist before it commits
TYPEMATIC_DELAY_MS = 500
TYPEMATIC_PERIOD_MS = 100   # ~10 chars/sec
SEND_QUEUE_MAX = 64
DEBUG = False           # print key events to the USB serial console
XT_CONNECTED = True     # driving the real Compaq now

# ----------------------------------------------------------------- XT pins
xt_clock = digitalio.DigitalInOut(board.GP21)
xt_clock.switch_to_output(value=True)   # PUSH-PULL: drives the SN74LVC07A input
xt_data = digitalio.DigitalInOut(board.GP22)
xt_data.switch_to_output(value=True)    # (open-drain behavior lives in the buffer,
                                        #  not the Pico -- the LVC07A input needs a
                                        #  clean CMOS drive, there is no pull-up here)
xt_reset = digitalio.DigitalInOut(board.GP20)
xt_reset.switch_to_input(pull=digitalio.Pull.UP)
xt_clock_sense = digitalio.DigitalInOut(board.GP26)
xt_clock_sense.switch_to_input(pull=digitalio.Pull.UP)

led = digitalio.DigitalInOut(board.LED)
led.switch_to_output(value=False)

# ----------------------------------------------------------------- matrix pins
ROW_PINS = (board.GP0, board.GP1, board.GP2, board.GP3, board.GP4,
            board.GP5, board.GP6, board.GP7, board.GP8, board.GP9)
COL_PINS = (board.GP10, board.GP11, board.GP12, board.GP13, board.GP14,
            board.GP15, board.GP16, board.GP17, board.GP18, board.GP19)

rows = []
for p in ROW_PINS:
    d = digitalio.DigitalInOut(p)
    d.switch_to_output(value=True)      # idle HIGH; active row driven LOW
    rows.append(d)
cols = []
for p in COL_PINS:
    d = digitalio.DigitalInOut(p)
    d.switch_to_input(pull=digitalio.Pull.UP)   # pressed reads LOW
    cols.append(d)

# ----------------------------------------------------------------- keymap
# (row, col) -> XT Set 1 make code. Break code = make | 0x80.
KEYMAP = {
    (0, 0): 0x3B,  # F1
    (0, 1): 0x3C,  # F2
    (0, 2): 0x01,  # Esc
    (0, 3): 0x02,  # 1
    (0, 4): 0x03,  # 2
    (0, 5): 0x04,  # 3
    (0, 6): 0x05,  # 4
    (0, 7): 0x06,  # 5
    (0, 8): 0x07,  # 6
    (1, 0): 0x08,  # 7
    (1, 1): 0x09,  # 8
    (1, 2): 0x0A,  # 9
    (1, 3): 0x0B,  # 0
    (1, 4): 0x0C,  # -
    (1, 5): 0x0D,  # =
    (1, 6): 0x0E,  # Backspace
    (1, 7): 0x45,  # numlock
    (1, 8): 0x46,  # scrollock
    (2, 0): 0x3D,  # F3
    (2, 1): 0x3E,  # F4
    (2, 2): 0x0F,  # Tab
    (2, 3): 0x10,  # Q
    (2, 4): 0x11,  # W
    (2, 5): 0x12,  # E
    (2, 6): 0x13,  # R
    (2, 7): 0x14,  # T
    (2, 8): 0x15,  # Y
    (2, 9): 0x16,  # U
    (3, 0): 0x17,  # I
    (3, 1): 0x18,  # O
    (3, 2): 0x19,  # P
    (3, 3): 0x1A,  # [
    (3, 4): 0x1B,  # ]
    (3, 5): 0x1C,  # ENTER
    (3, 6): 0x47,  # NP7
    (3, 7): 0x48,  # NP8
    (3, 8): 0x49,  # NP9
    (3, 9): 0x4A,  # NP-
    (4, 0): 0x3F,  # F5
    (4, 1): 0x40,  # F6
    (4, 2): 0x1D,  # CTRL
    (4, 3): 0x1E,  # A
    (4, 4): 0x1F,  # S
    (4, 5): 0x20,  # D
    (4, 6): 0x21,  # F
    (4, 7): 0x22,  # G
    (4, 8): 0x23,  # H
    (4, 9): 0x24,  # J
    (5, 0): 0x25,  # K
    (5, 1): 0x26,  # L
    (5, 2): 0x27,  # ;
    (5, 3): 0x28,  # '
    (5, 4): 0x29,  # `
    (5, 5): 0x4B,  # KP4
    (5, 6): 0x4C,  # KP5
    (5, 7): 0x4D,  # KP6
    (5, 8): 0x4E,  # KP+
    (6, 0): 0x41,  # F7
    (6, 1): 0x42,  # F8
    (6, 2): 0x2A,  # LSHIFT
    (6, 3): 0x2B,  # \
    (6, 4): 0x2C,  # Z
    (6, 5): 0x2D,  # X
    (6, 6): 0x2E,  # C
    (6, 7): 0x2F,  # V
    (6, 8): 0x30,  # B
    (6, 9): 0x31,  # N
    (7, 0): 0x32,  # M
    (7, 1): 0x33,  # ,
    (7, 2): 0x34,  # .
    (7, 3): 0x35,  # /
    (7, 4): 0x36,  # RSHIFT
    (7, 5): 0x37,  # */PRNTSCREEN
    (7, 6): 0x4F,  # NP1
    (7, 7): 0x50,  # NP2
    (7, 8): 0x51,  # NP3
    (8, 0): 0x43,  # F9
    (8, 1): 0x44,  # F10
    (8, 2): 0x38,  # ALT
    (8, 3): 0x39,  # SPACE
    (9, 0): 0x3A,  # CAPS
    (9, 1): 0x52,  # NP0
    (9, 2): 0x53,  # NP.
}

# modifiers / toggles that must NOT auto-repeat
NO_REPEAT = (0x2A, 0x36, 0x1D, 0x38, 0x3A, 0x45, 0x46)
CAPS = 0x3A

# ----------------------------------------------------------------- delays
def sleep_us(us):
    end = time.monotonic_ns() + int(us * 1000)
    while time.monotonic_ns() < end:
        pass

def sleep_ms(ms):
    end = time.monotonic_ns() + int(ms * 1_000_000)
    while time.monotonic_ns() < end:
        pass

# ----------------------------------------------------------------- XT tx
def xt_ready():
    return xt_reset.value and xt_clock_sense.value

def send_bit(bit):
    xt_data.value = bool(bit)
    sleep_us(SETUP_US)
    xt_clock.value = False               # FALLING EDGE -> host samples
    sleep_us(HALF_US)
    xt_clock.value = True
    sleep_us(HALF_US)

def send_byte(b):
    send_bit(1)
    for i in range(8):
        send_bit((b >> i) & 1)
    xt_data.value = True
    xt_clock.value = True

def do_bat():
    sleep_ms(BAT_DELAY_MS)
    if xt_ready():
        send_byte(0xAA)
        if DEBUG:
            print("BAT 0xAA")

# ----------------------------------------------------------------- send queue
_queue = []

def enqueue(b):
    if len(_queue) < SEND_QUEUE_MAX:
        _queue.append(b)
    elif DEBUG:
        print("queue full, dropping 0x%02X" % b)

def drain_queue():
    if not XT_CONNECTED:
        _queue.clear()          # bench mode: serial events only, never back up
        return
    # send as long as the host isn't holding us off
    while _queue and xt_ready():
        send_byte(_queue.pop(0))

# ----------------------------------------------------------------- scan/debounce
_raw_state = {}
_raw_pending = {}
state = {}       # (r,c) -> committed pressed bool
pending = {}     # (r,c) -> consecutive-scans-differing counter
for key in KEYMAP:
    state[key] = False
    pending[key] = 0

RAW_SCAN = False  # True: print (row,col) for every press, ignore KEYMAP gaps

def scan_and_emit():
    for r in range(10):
        rows[r].value = False                 # drive this row LOW
        sleep_us(3)                           # settle
        for c in range(10):
            key = (r, c)
            if RAW_SCAN:
                pressed = not cols[c].value
                if pressed != _raw_state.get(key, False):
                    _raw_pending[key] = _raw_pending.get(key, 0) + 1
                    if _raw_pending[key] >= DEBOUNCE_SCANS:
                        _raw_state[key] = pressed
                        _raw_pending[key] = 0
                        if pressed:
                            sc = KEYMAP.get(key)
                            tag = ("-> 0x%02X" % sc) if sc is not None else "(unmapped)"
                            print("row %d col %d  %s" % (r, c, tag))
                elif _raw_pending.get(key, 0) > 0:
                    _raw_pending[key] -= 1
                continue
            if key not in KEYMAP:
                continue
            pressed = not cols[c].value        # LOW == pressed
            if pressed != state[key]:
                pending[key] += 1                  # integrate toward the change
                if pending[key] >= DEBOUNCE_SCANS:
                    state[key] = pressed
                    pending[key] = 0
                    on_key_event(KEYMAP[key], pressed)
            elif pending[key] > 0:
                pending[key] -= 1                  # decay, don't hard-reset
        rows[r].value = True                  # release row

# ----------------------------------------------------------------- events
_repeat_code = None
_next_repeat = 0
_caps_on = False

def on_key_event(scancode, pressed):
    global _repeat_code, _next_repeat, _caps_on
    if pressed:
        enqueue(scancode)
        if DEBUG:
            print("make  0x%02X" % scancode)
        if scancode == CAPS:
            _caps_on = not _caps_on
            led.value = _caps_on
        if scancode not in NO_REPEAT:
            _repeat_code = scancode
            _next_repeat = time.monotonic_ns() + TYPEMATIC_DELAY_MS * 1_000_000
    else:
        enqueue(scancode | 0x80)
        if DEBUG:
            print("break 0x%02X" % (scancode | 0x80))
        if scancode == _repeat_code:
            _repeat_code = None

def typematic():
    global _next_repeat
    if _repeat_code is None:
        return
    now = time.monotonic_ns()
    if now >= _next_repeat:
        enqueue(_repeat_code)
        _next_repeat = now + TYPEMATIC_PERIOD_MS * 1_000_000

# ----------------------------------------------------------------- main
print("Compaq Portable keyboard firmware - matrix scan, XT out")
print("%d keys mapped" % len(KEYMAP))

prev_reset = xt_reset.value
if XT_CONNECTED and prev_reset:
    do_bat()

while True:
    if XT_CONNECTED:
        now_reset = xt_reset.value
        if now_reset and not prev_reset:
            if DEBUG:
                print("reset released")
            do_bat()
        prev_reset = now_reset

    scan_and_emit()
    typematic()
    drain_queue()

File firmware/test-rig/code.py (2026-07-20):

# code.py  --  Compaq Portable / IBM XT keyboard emulator (TEST RIG)
#              with PS/2 keyboard input  +  serial console fallback
#
# CircuitPython on a Raspberry Pi Pico.
#
# XT side (output to the Compaq) -- unchanged, validated on real hardware:
#     GP21  XT_CLOCK        open-drain out
#     GP22  XT_DATA         open-drain out
#     GP20  XT_RESET        input   (host drives; active LOW)
#     GP26  XT_CLOCK_SENSE  input   (reads XT clock, detects host inhibit)
#
# PS/2 side (input from a PS/2 keyboard):
#     GP18  PS2_CLOCK       in / open-drain out (in to read, low to inhibit)
#     GP19  PS2_DATA        input   (read-only; we never send commands)
#
# Level-shift the PS/2 5V clock/data through the same BSS138 approach.
# We act as a READ-ONLY PS/2 host: the keyboard powers up in Set 2 and sends
# scancodes on its own; we never send it commands, so there's no bidirectional
# handshake and no ACKs to service. We translate Set 2 -> XT Set 1 and clock
# the result out the XT side with the existing, proven send_byte().
#
# Serial console still works for injecting raw bytes / named keys. Type `help`.

import board
import digitalio
import supervisor
import sys
import time

# ----------------------------------------------------------------- timing
HALF_US = 20        # XT half clock period target
SETUP_US = 5        # XT data setup before falling edge
BAT_DELAY_MS = 170  # keyboard's wait after reset release
TAP_GAP_MS = 15     # gap between make and break for console `tap`
INHIBIT_TIMEOUT_MS = 1000
PS2_FRAME_TIMEOUT_MS = 6   # how long to wait for PS/2 activity per poll

# ----------------------------------------------------------------- XT pins
xt_clock = digitalio.DigitalInOut(board.GP21)
xt_clock.switch_to_output(value=True, drive_mode=digitalio.DriveMode.OPEN_DRAIN)

xt_data = digitalio.DigitalInOut(board.GP22)
xt_data.switch_to_output(value=True, drive_mode=digitalio.DriveMode.OPEN_DRAIN)

xt_reset = digitalio.DigitalInOut(board.GP20)
xt_reset.switch_to_input(pull=digitalio.Pull.UP)

xt_clock_sense = digitalio.DigitalInOut(board.GP26)
xt_clock_sense.switch_to_input(pull=digitalio.Pull.UP)

# ----------------------------------------------------------------- PS/2 pins
ps2_clock = digitalio.DigitalInOut(board.GP18)
ps2_clock.switch_to_input(pull=digitalio.Pull.UP)

ps2_data = digitalio.DigitalInOut(board.GP19)
ps2_data.switch_to_input(pull=digitalio.Pull.UP)


# ----------------------------------------------------------------- delays
def sleep_us(us):
    end = time.monotonic_ns() + int(us * 1000)
    while time.monotonic_ns() < end:
        pass


def sleep_ms(ms):
    end = time.monotonic_ns() + int(ms * 1_000_000)
    while time.monotonic_ns() < end:
        pass


# ----------------------------------------------------------------- PS/2 inhibit
def ps2_inhibit(on):
    """Hold PS/2 clock low so the keyboard buffers, or release it to receive."""
    if on:
        ps2_clock.switch_to_output(
            value=False, drive_mode=digitalio.DriveMode.OPEN_DRAIN)
    else:
        ps2_clock.switch_to_input(pull=digitalio.Pull.UP)


# ----------------------------------------------------------------- XT tx
def wait_clock_free(timeout_ms=INHIBIT_TIMEOUT_MS):
    end = time.monotonic_ns() + timeout_ms * 1_000_000
    while not xt_clock_sense.value:       # low == host inhibiting
        if time.monotonic_ns() > end:
            return False
    return True


def send_bit(bit):
    xt_data.value = bool(bit)
    sleep_us(SETUP_US)
    xt_clock.value = False                # FALLING EDGE -> host samples
    sleep_us(HALF_US)
    xt_clock.value = True
    sleep_us(HALF_US)


def send_byte(b):
    """One XT frame: start bit + 8 data bits LSB first. PS/2 is inhibited for
    the duration so an incoming keystroke can't collide with transmission."""
    if not xt_reset.value:
        print("  [xt reset asserted - dropping 0x%02X]" % b)
        return False
    ps2_inhibit(True)
    try:
        if not wait_clock_free():
            print("  [xt clock inhibited - dropping 0x%02X]" % b)
            return False
        send_bit(1)
        for i in range(8):
            send_bit((b >> i) & 1)
        xt_data.value = True
        xt_clock.value = True
        return True
    finally:
        ps2_inhibit(False)


def tap(scancode, gap_ms=TAP_GAP_MS):
    if send_byte(scancode):
        sleep_ms(gap_ms)
        send_byte(scancode | 0x80)


def do_bat():
    print("  BAT: waiting %d ms then sending 0xAA..." % BAT_DELAY_MS)
    sleep_ms(BAT_DELAY_MS)
    if send_byte(0xAA):
        print("  BAT: 0xAA sent")


# ----------------------------------------------------------------- PS/2 rx
def ps2_read_byte(timeout_ms=PS2_FRAME_TIMEOUT_MS):
    """Read one PS/2 frame (device->host). Returns the data byte, or None on
    timeout / framing error / parity error.

    Frame = start(0) + 8 data LSB-first + odd parity + stop(1), keyboard-
    clocked. Data is valid while clock is low, so we sample after each
    falling edge."""
    end = time.monotonic_ns() + timeout_ms * 1_000_000

    while not ps2_clock.value:             # ensure idle-high first
        if time.monotonic_ns() > end:
            return None
    while ps2_clock.value:                 # wait for start-bit falling edge
        if time.monotonic_ns() > end:
            return None

    samples = [1 if ps2_data.value else 0]   # start bit
    for _ in range(10):                      # 8 data + parity + stop
        while not ps2_clock.value:
            if time.monotonic_ns() > end:
                return None
        while ps2_clock.value:
            if time.monotonic_ns() > end:
                return None
        samples.append(1 if ps2_data.value else 0)

    if samples[0] != 0 or samples[10] != 1:  # start/stop framing
        return None
    data = 0
    for i in range(8):
        data |= samples[1 + i] << i
    ones = 0                                 # odd-parity check
    v = data
    while v:
        ones += v & 1
        v >>= 1
    if (ones + samples[9]) % 2 == 0:
        return None
    return data
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
